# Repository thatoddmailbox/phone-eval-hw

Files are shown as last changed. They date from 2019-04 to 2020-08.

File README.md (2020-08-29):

# phone-eval-hw
The evaluation board for the [phone I built](https://github.com/thatoddmailbox/phone). [View PDF schematic](./thingb-eval-hw.pdf)

This was the first version of the hardware. The idea was to make sure that things were working in a more open (and therefore easier to assemble/test/debug) design before making a smaller, more portable version. It also allowed some problems to be caught and addressed for the next revision.

There are a [couple of known issues](https://github.com/thatoddmailbox/phone-eval-hw/issues/1) with this hardware. The biggest issue is that the battery charging IC, while theoretically capable of charging the battery at 1A, quickly gets too hot and throttles itself when charging. These issues were fixed in the [next revision](https://github.com/thatoddmailbox/phone-hw), which also had the correct form factor.

(note: this was originally called thingb-eval-hw because I thought I'd come up with a more creative name than "phone". I did not.)

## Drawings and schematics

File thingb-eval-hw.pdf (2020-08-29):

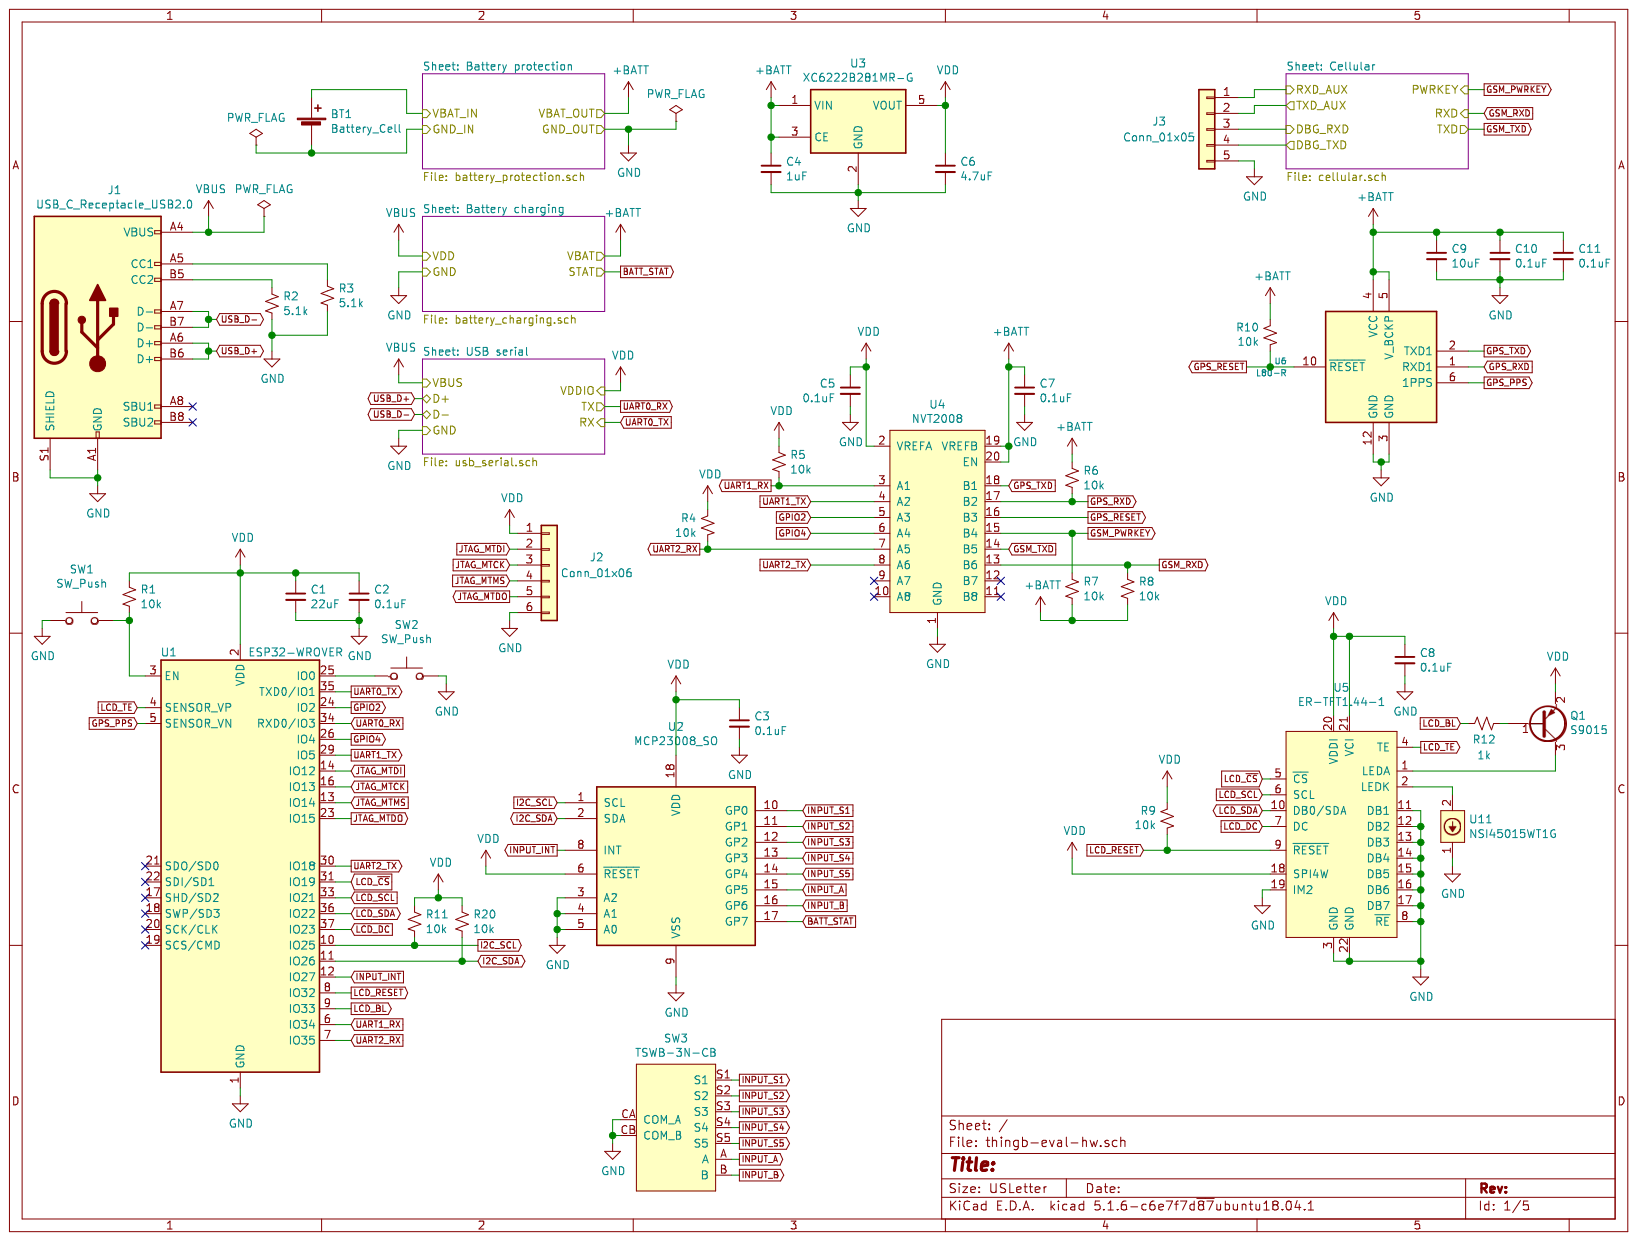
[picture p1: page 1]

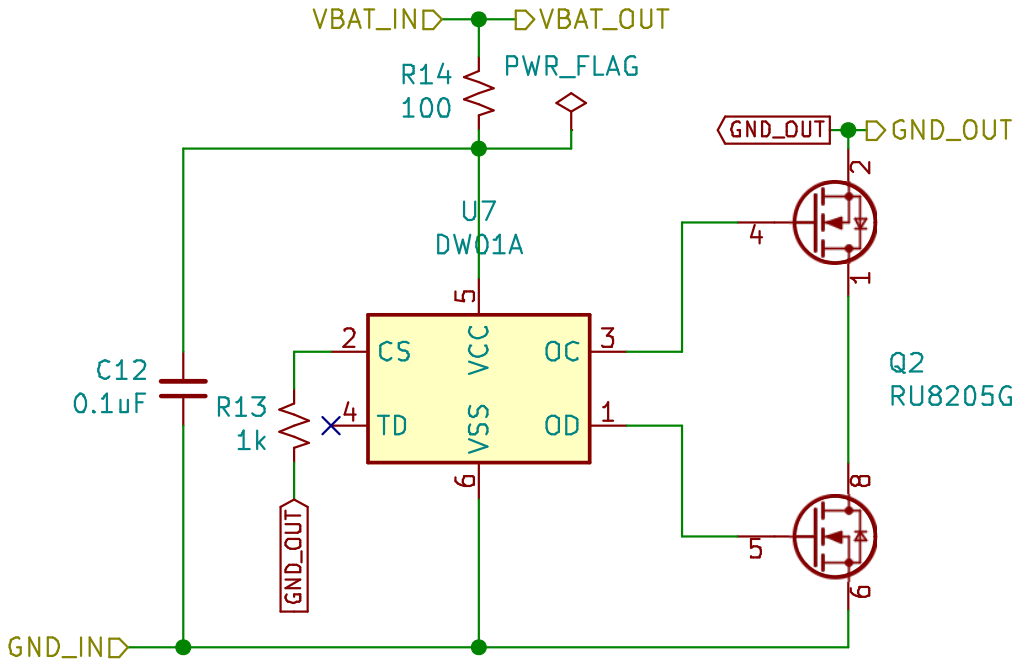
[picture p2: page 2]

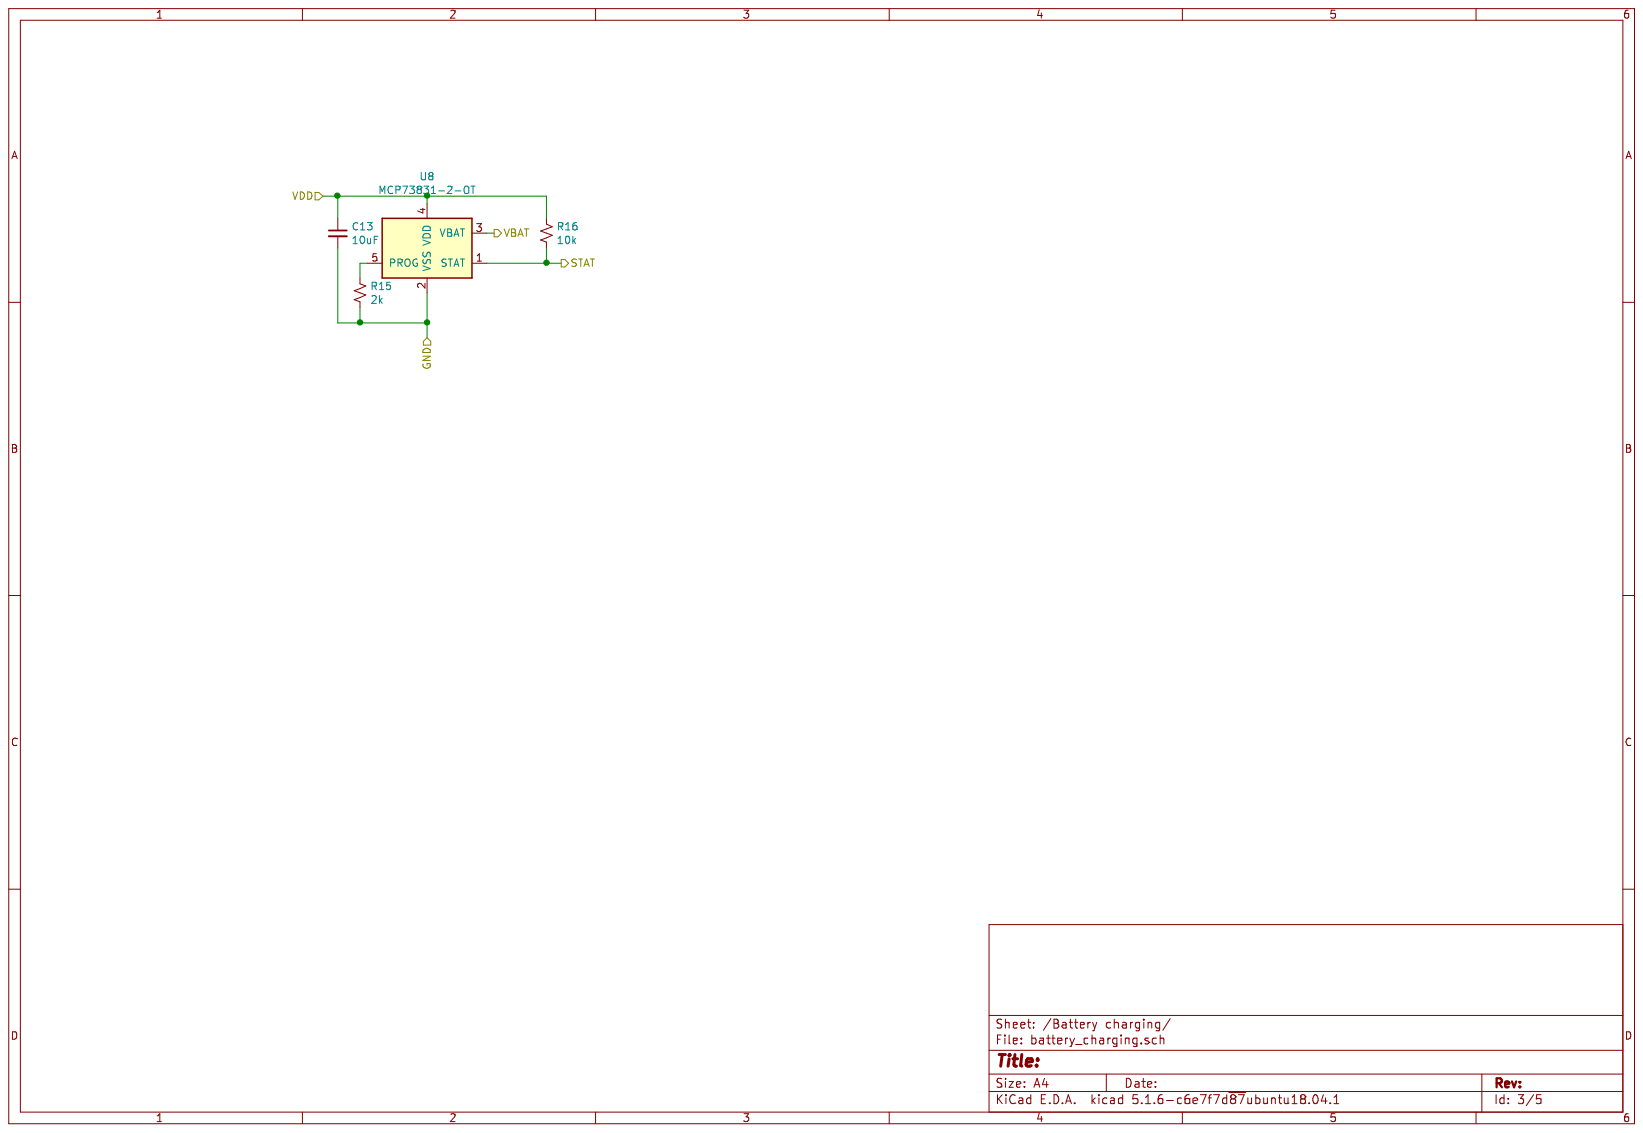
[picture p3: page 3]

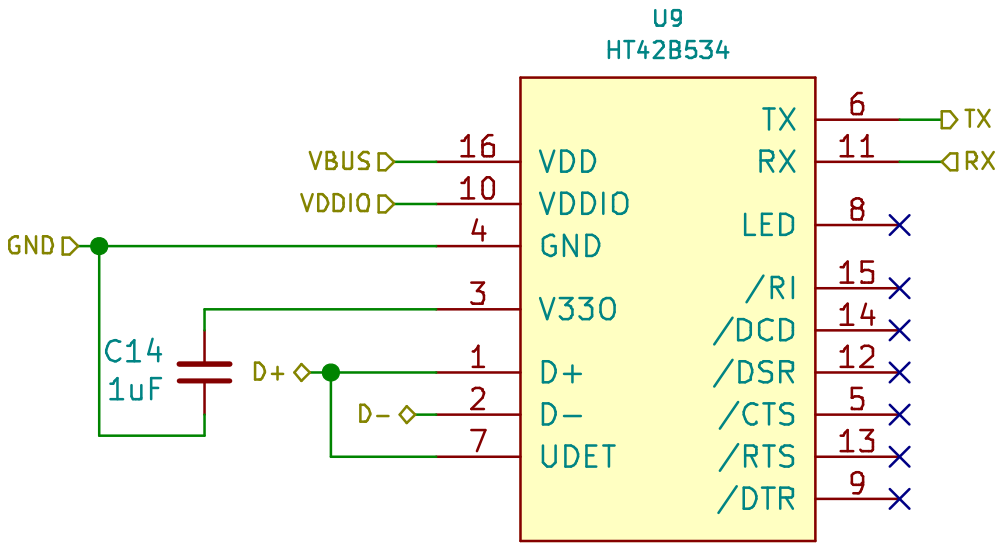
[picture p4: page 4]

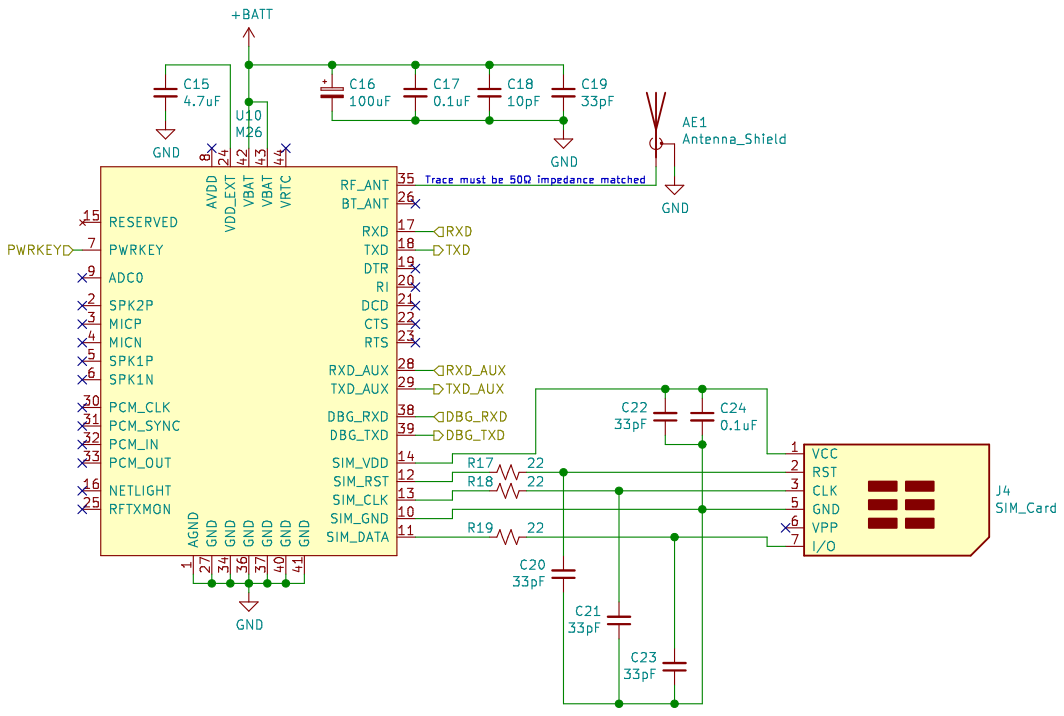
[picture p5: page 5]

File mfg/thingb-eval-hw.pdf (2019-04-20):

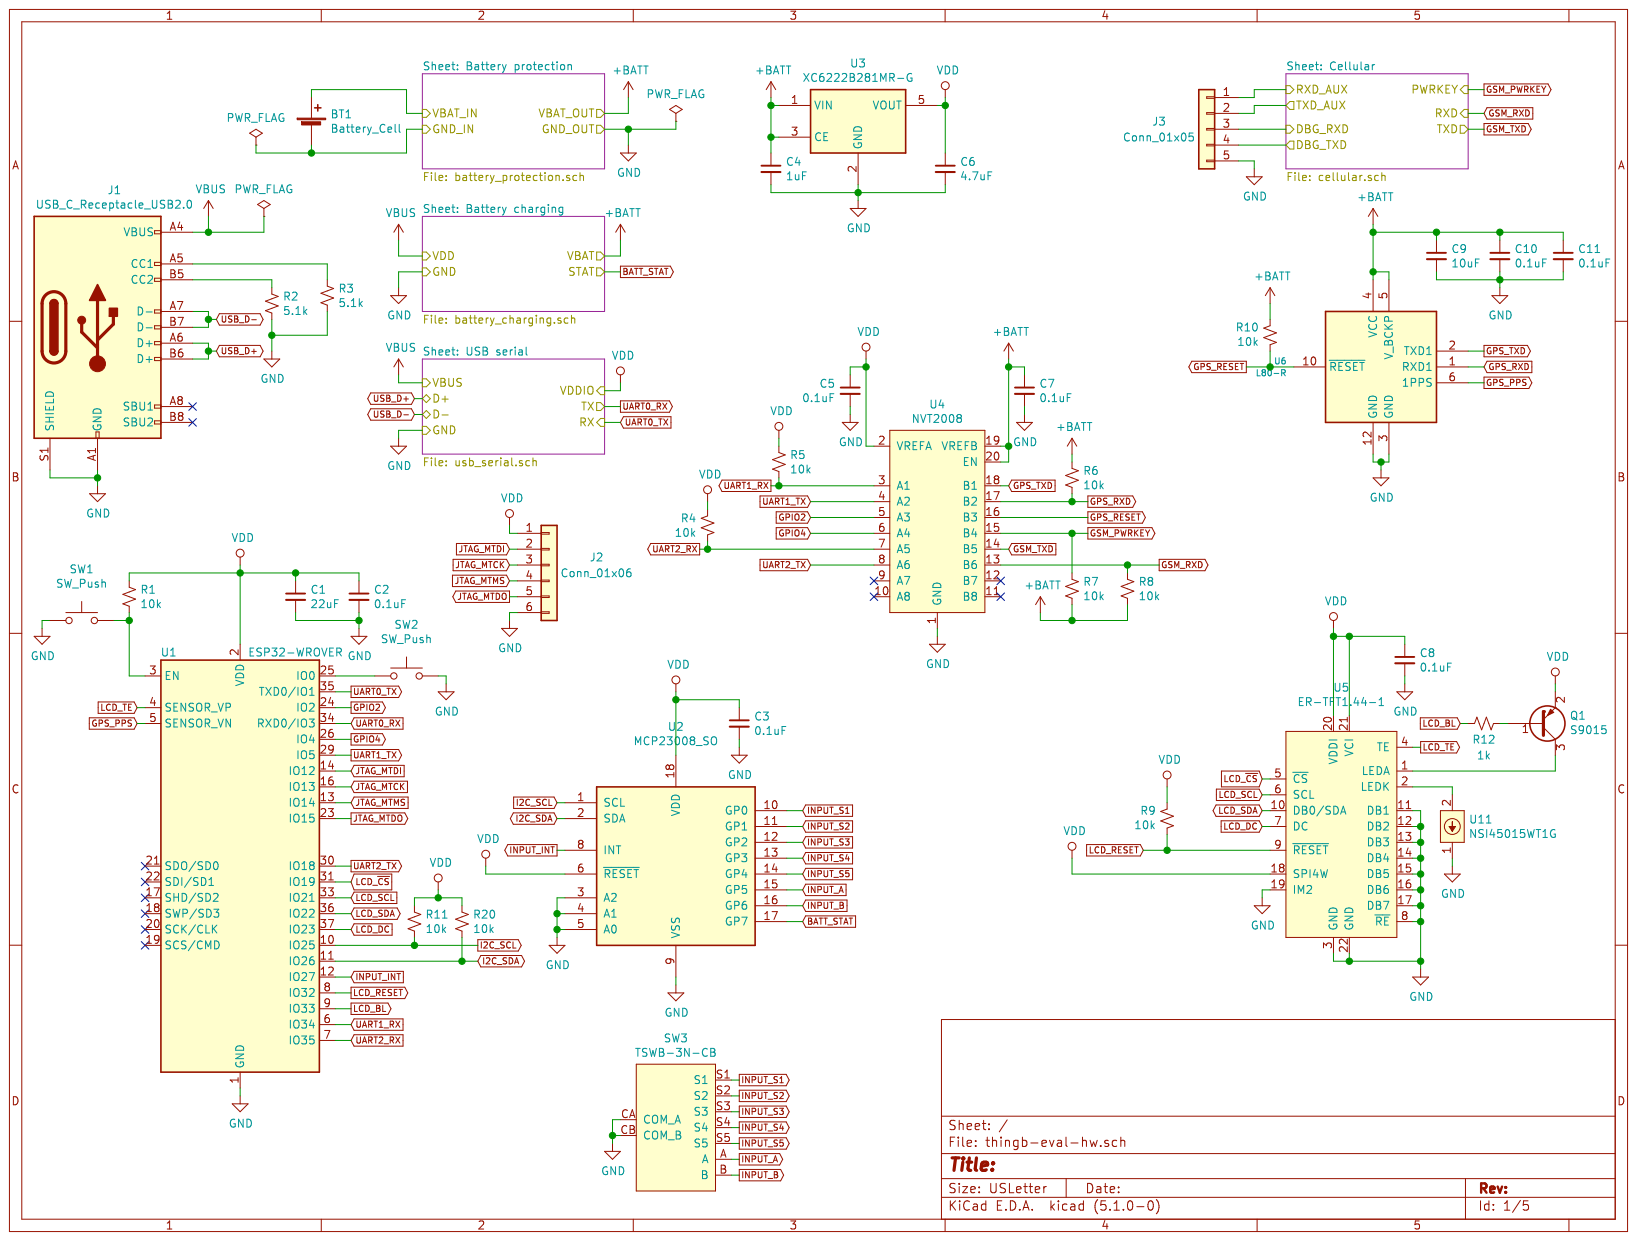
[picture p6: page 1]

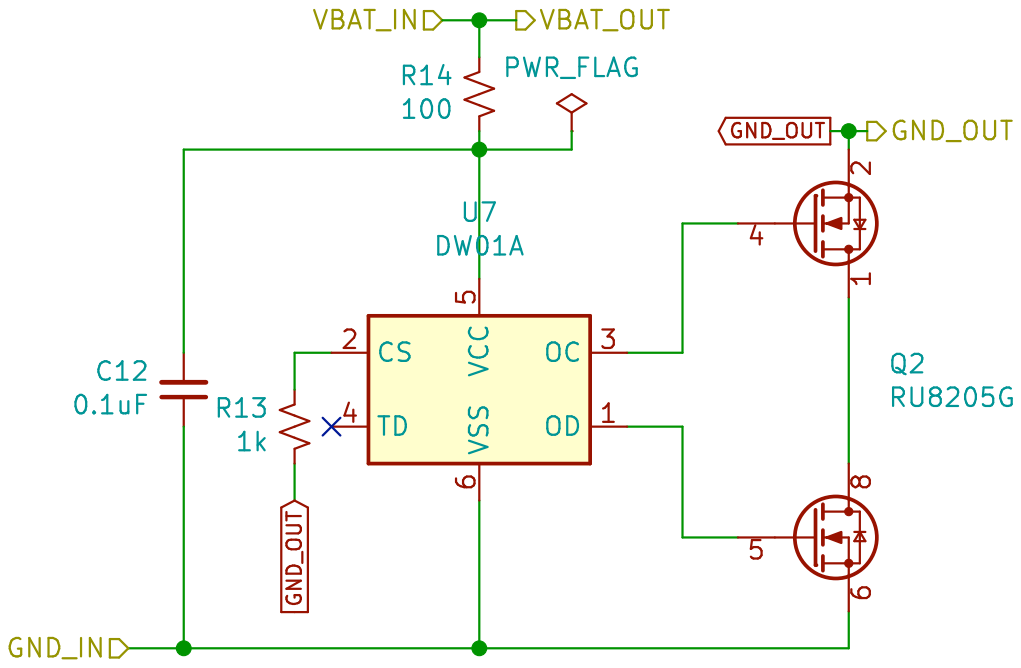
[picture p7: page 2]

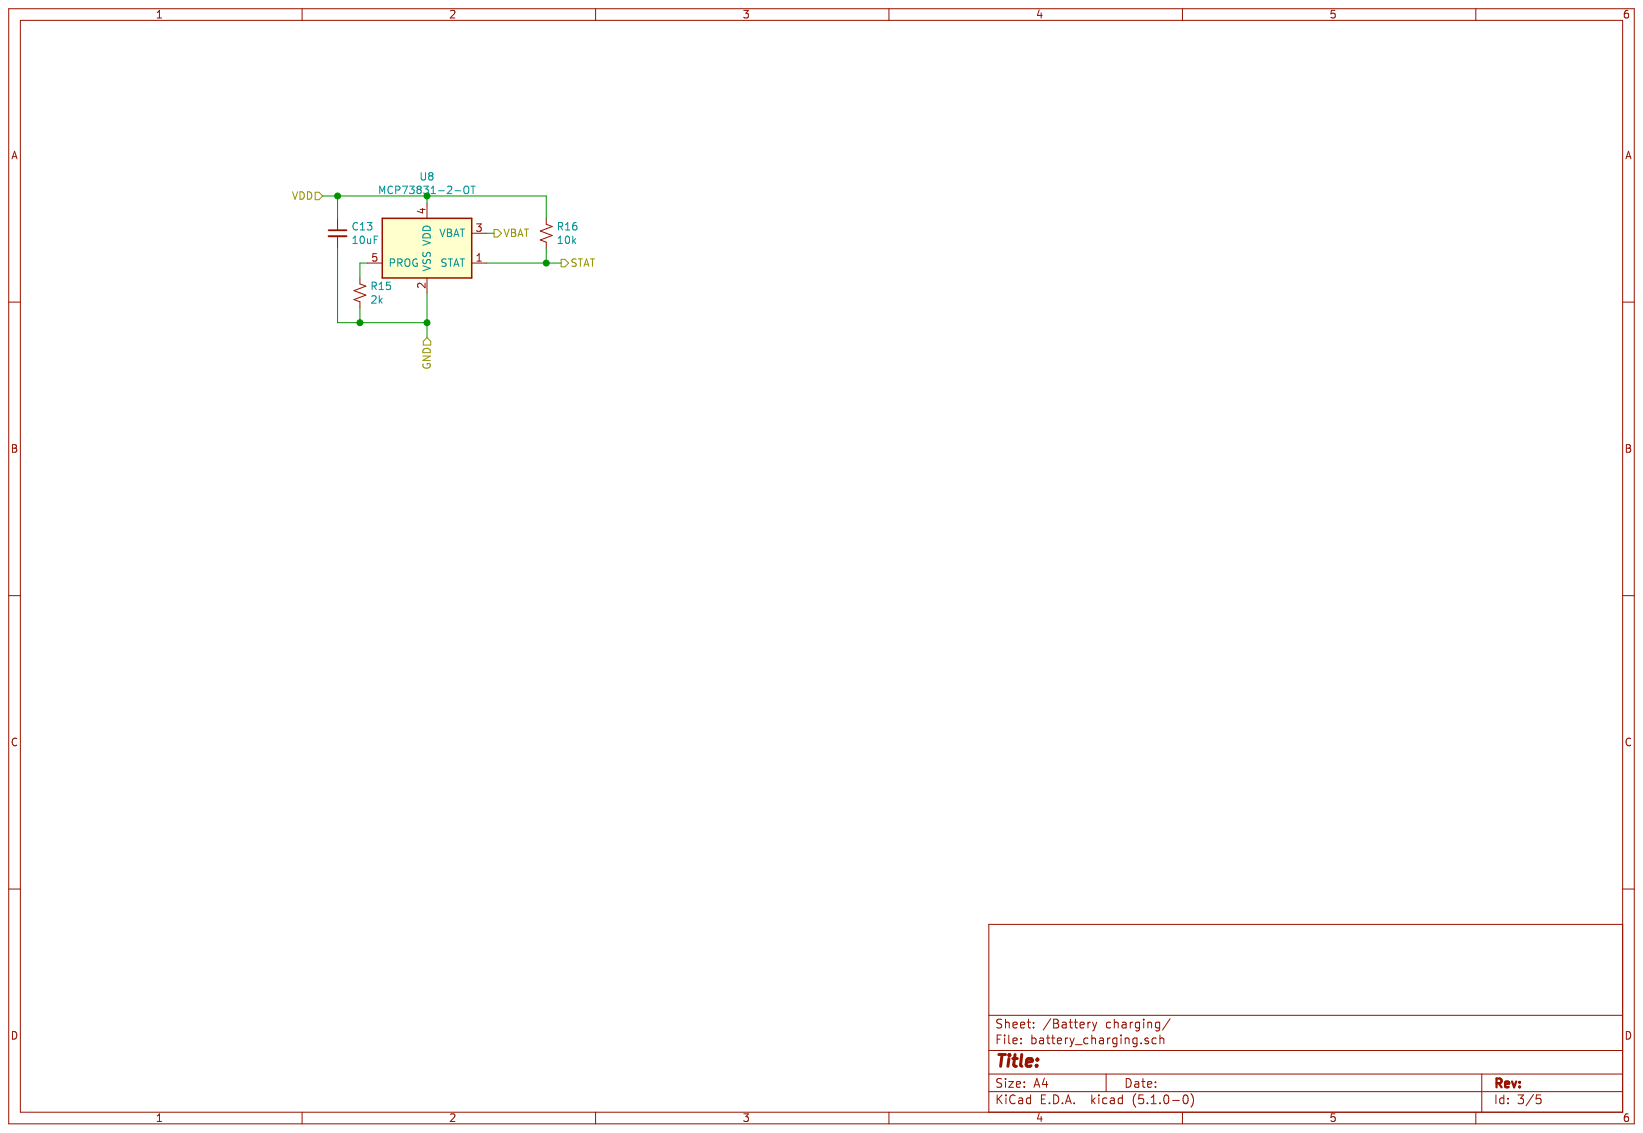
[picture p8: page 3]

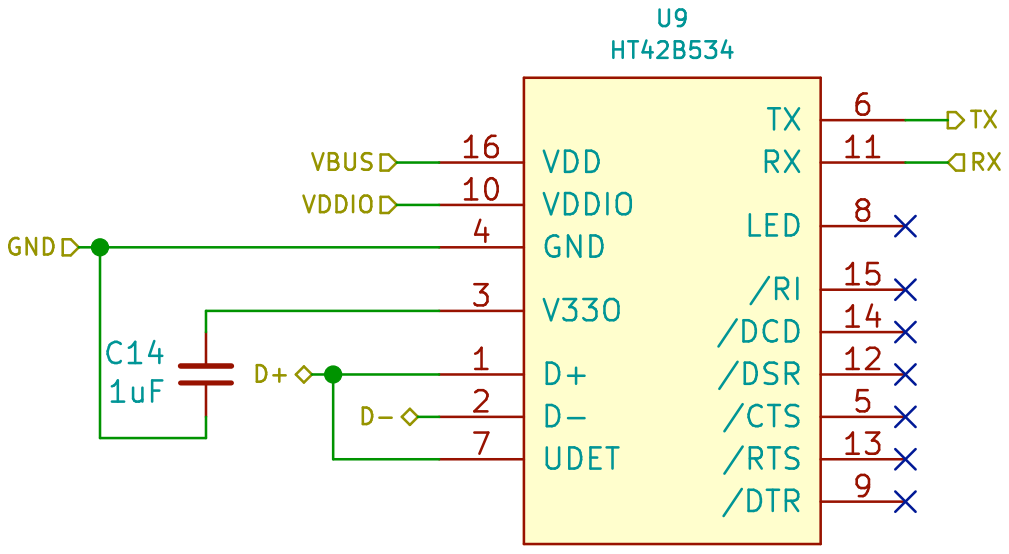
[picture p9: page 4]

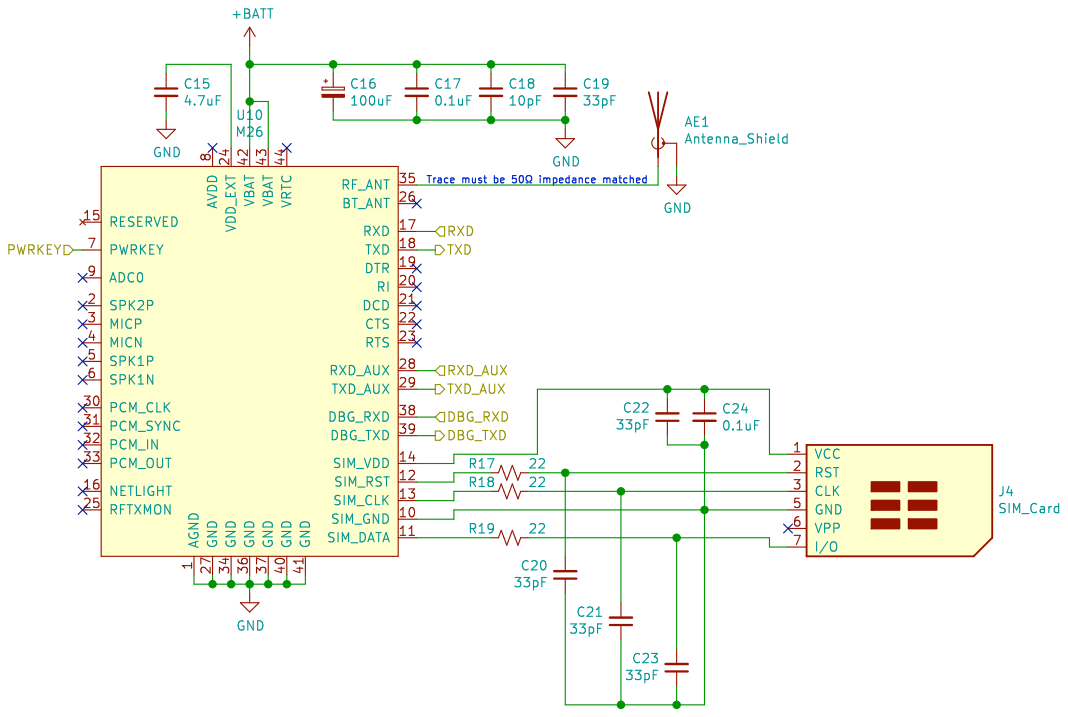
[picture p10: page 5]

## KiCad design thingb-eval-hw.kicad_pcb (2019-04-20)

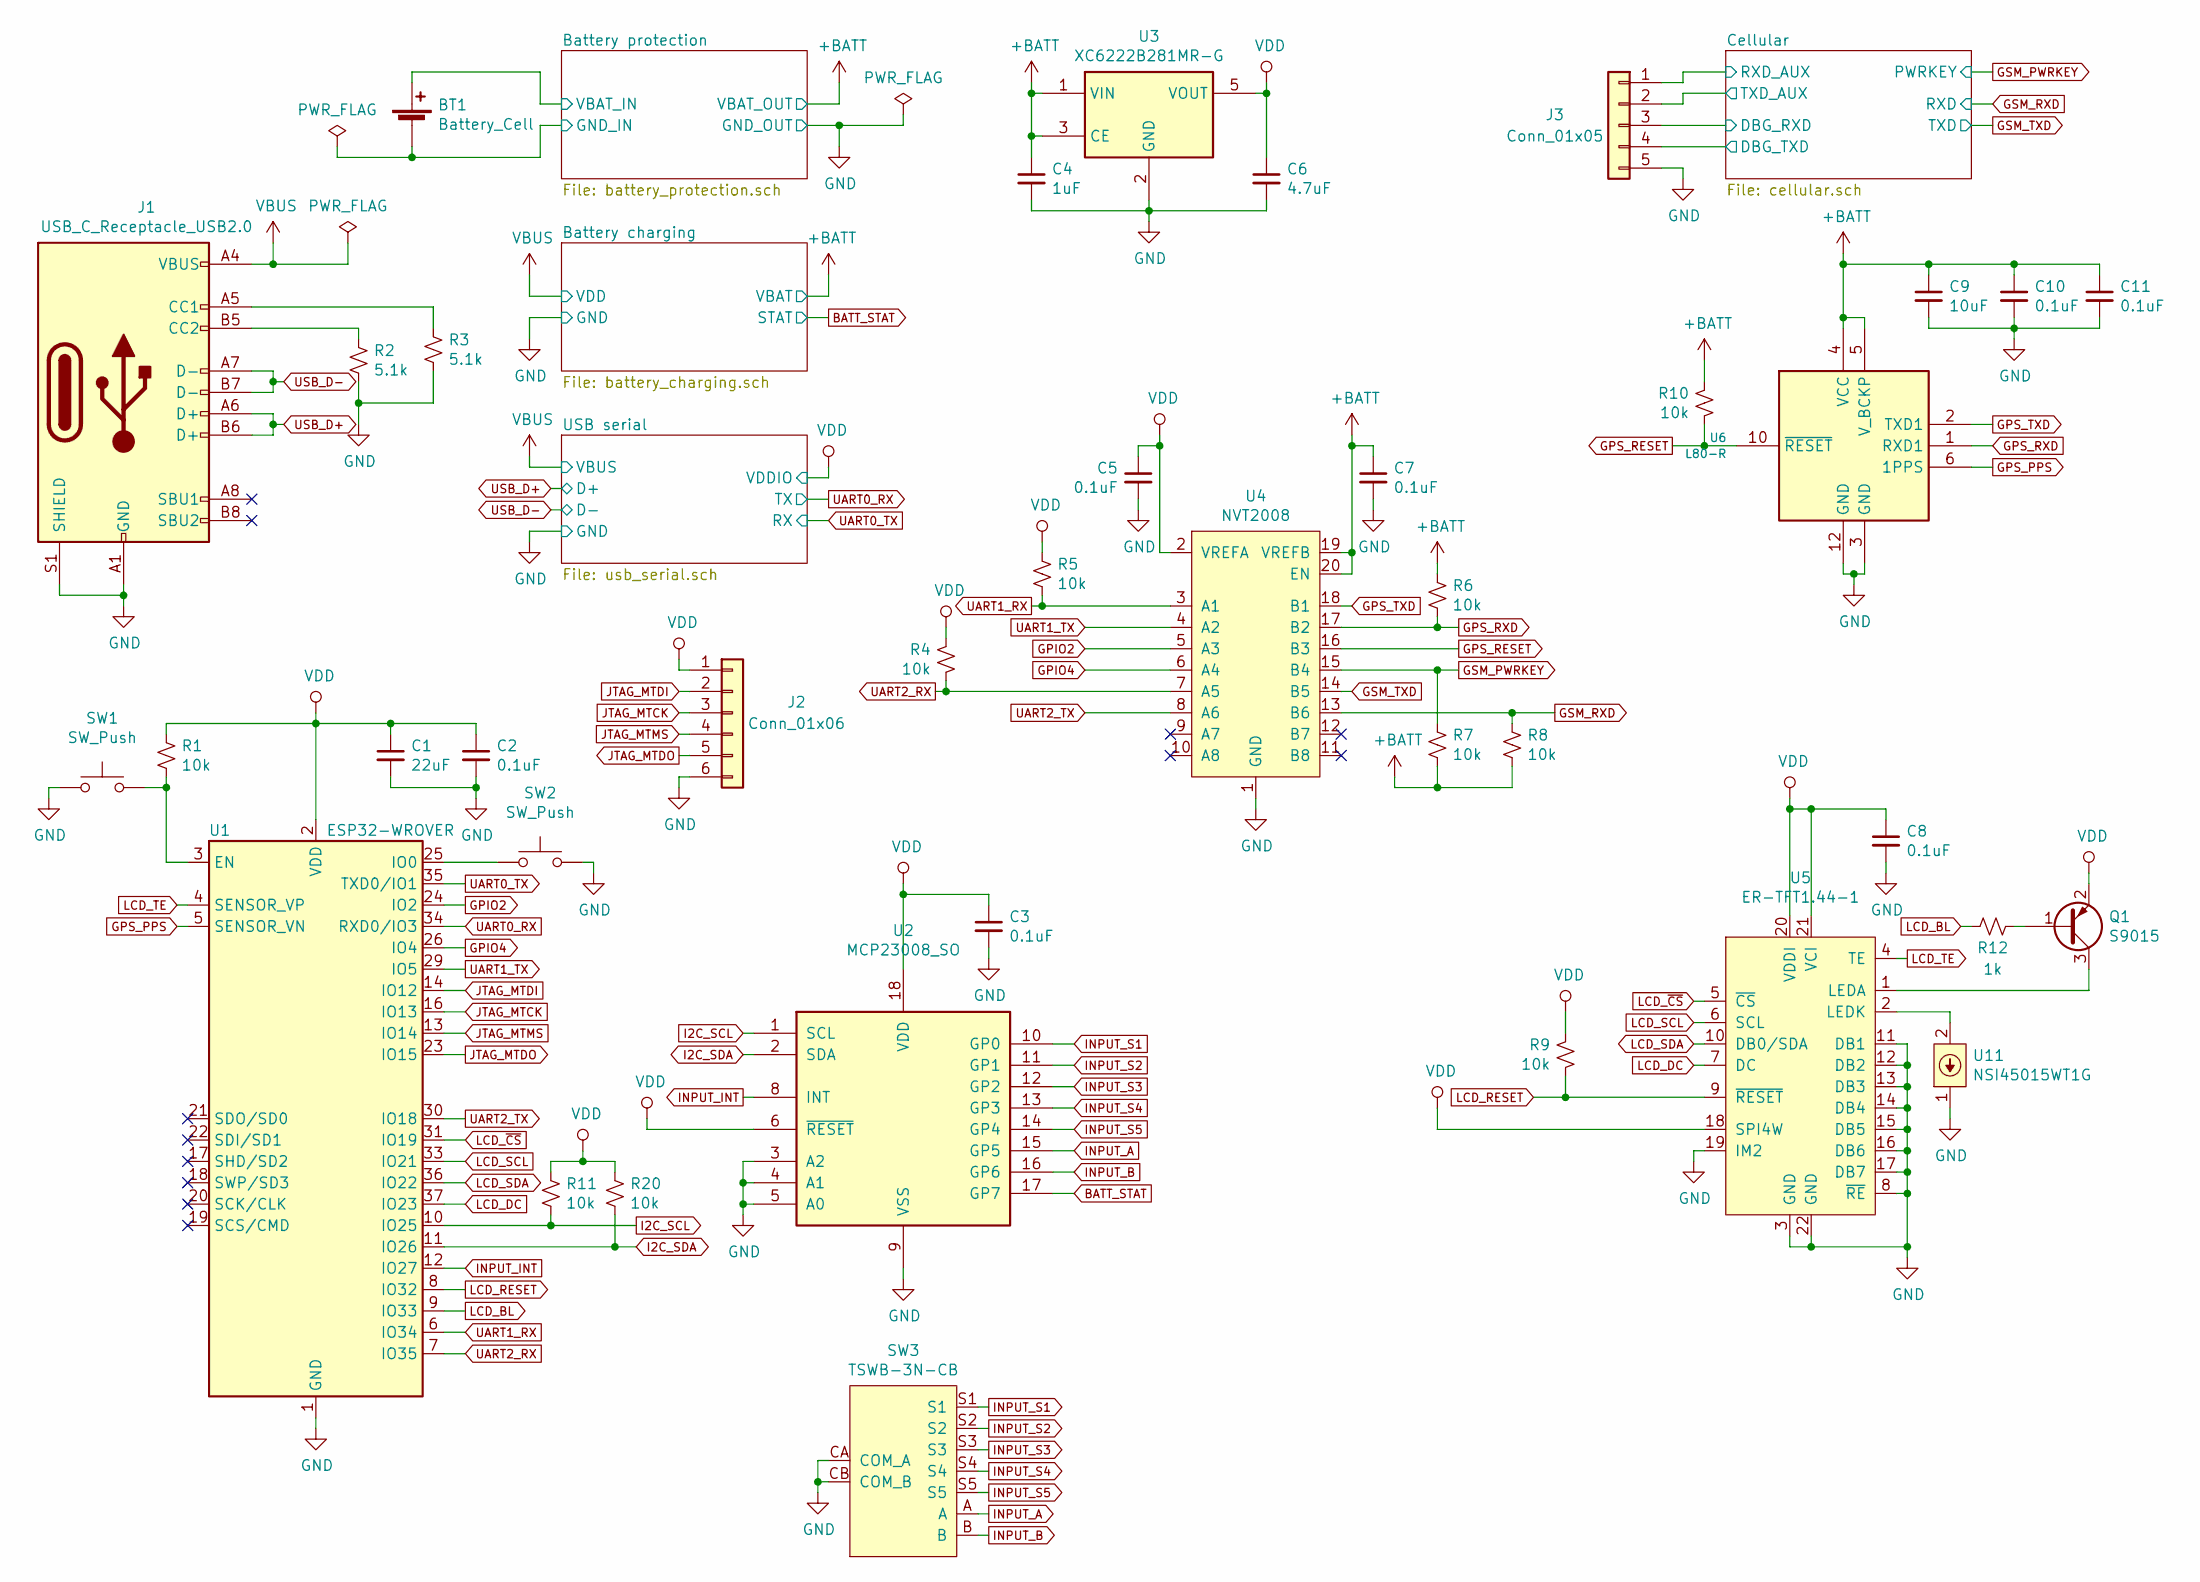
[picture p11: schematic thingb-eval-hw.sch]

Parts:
BT1: Battery_Cell; PinHeader_1x02_P2.54mm_Vertical
C1: 22uF; C_0603_1608Metric_Pad1.05x0.95mm_HandSolder
C2, C3, C5, C7, C8, C10, C11: 0.1uF; C_0603_1608Metric_Pad1.05x0.95mm_HandSolder
C4: 1uF; C_0603_1608Metric_Pad1.05x0.95mm_HandSolder
C6: 4.7uF; C_0603_1608Metric_Pad1.05x0.95mm_HandSolder
C9: 10uF; C_0603_1608Metric_Pad1.05x0.95mm_HandSolder
J1: USB_C_Receptacle_USB2.0; U262-16XN-4BVC11
J2: Conn_01x06; PinHeader_1x06_P2.54mm_Vertical
J3: Conn_01x05; PinHeader_1x05_P2.54mm_Vertical
Q1: S9015; SOT-23_Handsoldering
R1, R4, R5, R6, R7, R8, R9, R10, R11, R20: 10k; R_0603_1608Metric_Pad1.05x0.95mm_HandSolder
R2, R3: 5.1k; R_0603_1608Metric_Pad1.05x0.95mm_HandSolder
R12: 1k; R_0603_1608Metric_Pad1.05x0.95mm_HandSolder
SW1, SW2: SW_Push; SW_SPST_EVQPE1
SW3: TSWB-3N-CB
U1: ESP32-WROVER
U2: MCP23008_SO; SOIC-18W_7.5x11.6mm_P1.27mm
U3: XC6222B281MR-G; SOT-23-5
U4: NVT2008; TSSOP-20_4.4x6.5mm_P0.65mm
U5: ER-TFT1.44-1
U6: L80-R
U11: NSI45015WT1G; D_SOD-123

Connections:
+BATT: BT1.1 (+), C4.1, C7.1, C9.1, C10.1, C11.1, R6.1, R7.2, R8.2, R10.2, U3.1 (VIN), U3.3 (CE), U4.19 (VREFB), U4.20 (EN), U6.4 (VCC), U6.5 (V_BCKP); also elsewhere on the board
/Battery protection/GND_IN: BT1.2 (-); also elsewhere on the board
/Cellular/DBG_RXD: J3.3; also elsewhere on the board
/Cellular/DBG_TXD: J3.4; also elsewhere on the board
/Cellular/RXD_AUX: J3.1; also elsewhere on the board
/Cellular/TXD_AUX: J3.2; also elsewhere on the board
BATT_STAT: U2.17 (GP7); also elsewhere on the board
GND_OUT: C1.2, C2.2, C3.2, C4.2, C5.2, C6.2, C7.2, C8.2, C9.2, C10.2, C11.2, J1.A1 (GND), J1.A12 (GND), J1.B1 (GND), J1.B12 (GND), J1.S1 (SHIELD), J2.6, J3.5, R2.2, R3.2, SW1.2, SW2.2, SW3.CA (COM_A), SW3.CB (COM_B), U1.1 (GND), U1.15 (GND), U1.38 (GND), U2.3 (A2), U2.4 (A1), U2.5 (A0), U2.9 (VSS), U3.2 (GND), U4.1 (GND), U5.3 (GND), U5.8 (~RE), U5.11 (DB1), U5.12 (DB2), U5.13 (DB3), U5.14 (DB4), U5.15 (DB5), U5.16 (DB6), U5.17 (DB7), U5.19 (IM2), U5.22 (GND), U6.3 (GND), U6.12 (GND), U11.1; also elsewhere on the board
GPIO2: U1.24 (IO2), U4.5 (A3)
GPIO4: U1.26 (IO4), U4.6 (A4)
GPS_PPS: U1.5 (SENSOR_VN), U6.6 (1PPS)
GPS_RESET: R10.1, U4.16 (B3), U6.10 (~RESET)
GPS_RXD: R6.2, U4.17 (B2), U6.1 (RXD1)
GPS_TXD: U4.18 (B1), U6.2 (TXD1)
GSM_PWRKEY: R7.1, U4.15 (B4); also elsewhere on the board
GSM_RXD: R8.1, U4.13 (B6); also elsewhere on the board
GSM_TXD: U4.14 (B5); also elsewhere on the board
I2C_SCL: R11.2, U1.10 (IO25), U2.1 (SCL)
I2C_SDA: R20.2, U1.11 (IO26), U2.2 (SDA)
INPUT_A: SW3.A, U2.15 (GP5)
INPUT_B: SW3.B, U2.16 (GP6)
INPUT_INT: U1.12 (IO27), U2.8 (INT)
INPUT_S1: SW3.S1, U2.10 (GP0)
INPUT_S2: SW3.S2, U2.11 (GP1)
INPUT_S3: SW3.S3, U2.12 (GP2)
INPUT_S4: SW3.S4, U2.13 (GP3)
INPUT_S5: SW3.S5, U2.14 (GP4)
JTAG_MTCK: J2.3, U1.16 (IO13)
JTAG_MTDI: J2.2, U1.14 (IO12)
JTAG_MTDO: J2.5, U1.23 (IO15)
JTAG_MTMS: J2.4, U1.13 (IO14)
LCD_BL: R12.2, U1.9 (IO33)
LCD_DC: U1.37 (IO23), U5.7 (DC)
LCD_RESET: R9.1, U1.8 (IO32), U5.9 (~RESET)
LCD_SCL: U1.33 (IO21), U5.6 (SCL)
LCD_SDA: U1.36 (IO22), U5.10 (DB0/SDA)
LCD_TE: U1.4 (SENSOR_VP), U5.4 (TE)
LCD_~CS: U1.31 (IO19), U5.5 (~CS)
unnamed: J1.A5 (CC1), R3.1
unnamed: J1.B5 (CC2), R2.1
unnamed: Q1.1 (B), R12.1
unnamed: Q1.3 (C), U5.1 (LEDA)
unnamed: R1.2, SW1.1, U1.3 (EN)
unnamed: SW2.1, U1.25 (IO0)
unnamed: U5.2 (LEDK), U11.2
UART0_RX: U1.34 (RXD0/IO3); also elsewhere on the board
UART0_TX: U1.35 (TXD0/IO1); also elsewhere on the board
UART1_RX: R5.2, U1.6 (IO34), U4.3 (A1)
UART1_TX: U1.29 (IO5), U4.4 (A2)
UART2_RX: R4.2, U1.7 (IO35), U4.7 (A5)
UART2_TX: U1.30 (IO18), U4.8 (A6)
USB_D+: J1.A6 (D+), J1.B6 (D+); also elsewhere on the board
USB_D-: J1.A7 (D-), J1.B7 (D-); also elsewhere on the board
VBUS: J1.A4 (VBUS), J1.A9 (VBUS), J1.B4 (VBUS), J1.B9 (VBUS); also elsewhere on the board
VDD: C1.1, C2.1, C3.1, C5.1, C6.1, C8.1, J2.1, Q1.2 (E), R1.1, R4.1, R5.1, R9.2, R11.1, R20.1, U1.2 (VDD), U2.6 (~RESET~), U2.18 (VDD), U3.5 (VOUT), U4.2 (VREFA), U5.18 (SPI4W), U5.20 (VDDI), U5.21 (VCI); also elsewhere on the board

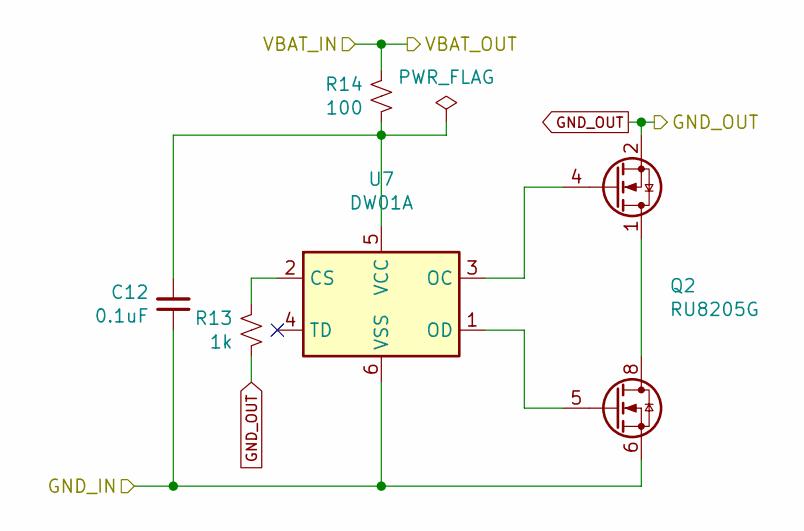
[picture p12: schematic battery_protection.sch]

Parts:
C12: 0.1uF; C_0603_1608Metric_Pad1.05x0.95mm_HandSolder
Q2: RU8205G; TSSOP-8_4.4x3mm_P0.65mm
R13: 1k; R_0603_1608Metric_Pad1.05x0.95mm_HandSolder
R14: 100; R_0603_1608Metric_Pad1.05x0.95mm_HandSolder
U7: DW01A; SOT-23-6

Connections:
+BATT: R14.2; also elsewhere on the board
/Battery protection/GND_IN: C12.1, Q2.6 (S2), Q2.7 (S2), U7.6 (VSS); also elsewhere on the board
GND_OUT: Q2.2 (S1), Q2.3 (S1), R13.1; also elsewhere on the board
unnamed: C12.2, R14.1, U7.5 (VCC)
unnamed: Q2.1 (D1), Q2.8 (D2)
unnamed: Q2.4 (G1), U7.3 (OC)
unnamed: Q2.5 (G2), U7.1 (OD)
unnamed: R13.2, U7.2 (CS)

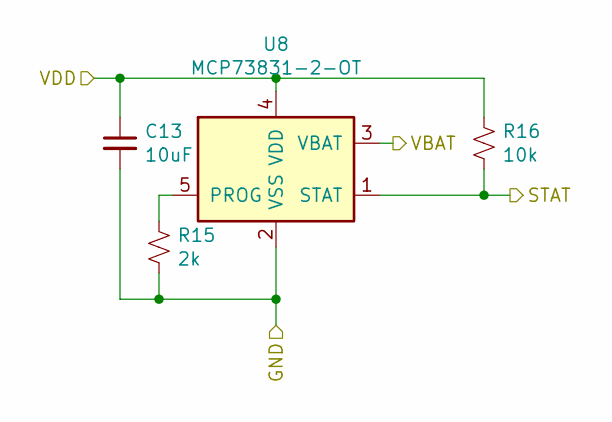
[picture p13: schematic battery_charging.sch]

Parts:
C13: 10uF; C_0603_1608Metric_Pad1.05x0.95mm_HandSolder
R15: 2k; R_0603_1608Metric_Pad1.05x0.95mm_HandSolder
R16: 10k; R_0603_1608Metric_Pad1.05x0.95mm_HandSolder
U8: MCP73831-2-OT; SOT-23-5

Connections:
+BATT: U8.3 (VBAT); also elsewhere on the board
BATT_STAT: R16.2, U8.1 (STAT); also elsewhere on the board
GND_OUT: C13.2, R15.2, U8.2 (VSS); also elsewhere on the board
unnamed: R15.1, U8.5 (PROG)
VBUS: C13.1, R16.1, U8.4 (VDD); also elsewhere on the board

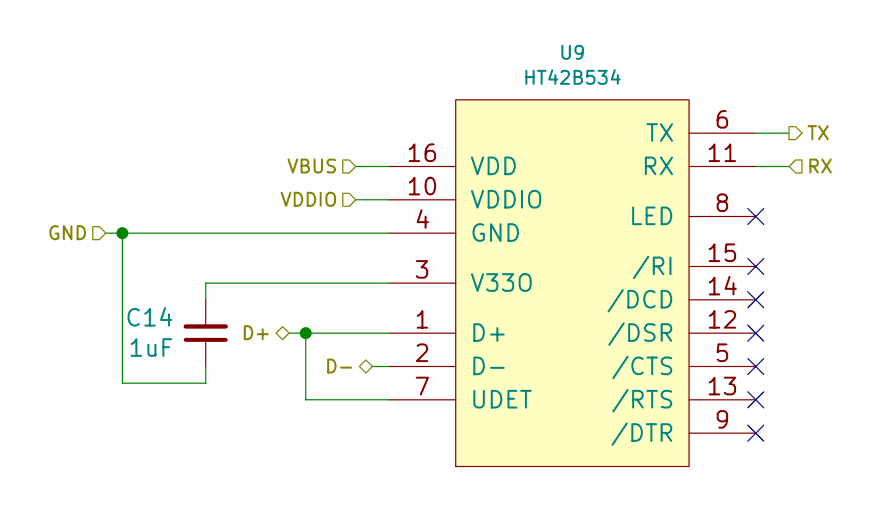
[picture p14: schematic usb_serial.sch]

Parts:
C14: 1uF; C_0603_1608Metric_Pad1.05x0.95mm_HandSolder
U9: HT42B534; SOIC-16_3.9x9.9mm_P1.27mm

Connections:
GND_OUT: C14.1, U9.4 (GND); also elsewhere on the board
unnamed: C14.2, U9.3 (V33O)
UART0_RX: U9.6 (TX); also elsewhere on the board
UART0_TX: U9.11 (RX); also elsewhere on the board
USB_D+: U9.1 (D+), U9.7 (UDET); also elsewhere on the board
USB_D-: U9.2 (D-); also elsewhere on the board
VBUS: U9.16 (VDD); also elsewhere on the board
VDD: U9.10 (VDDIO); also elsewhere on the board

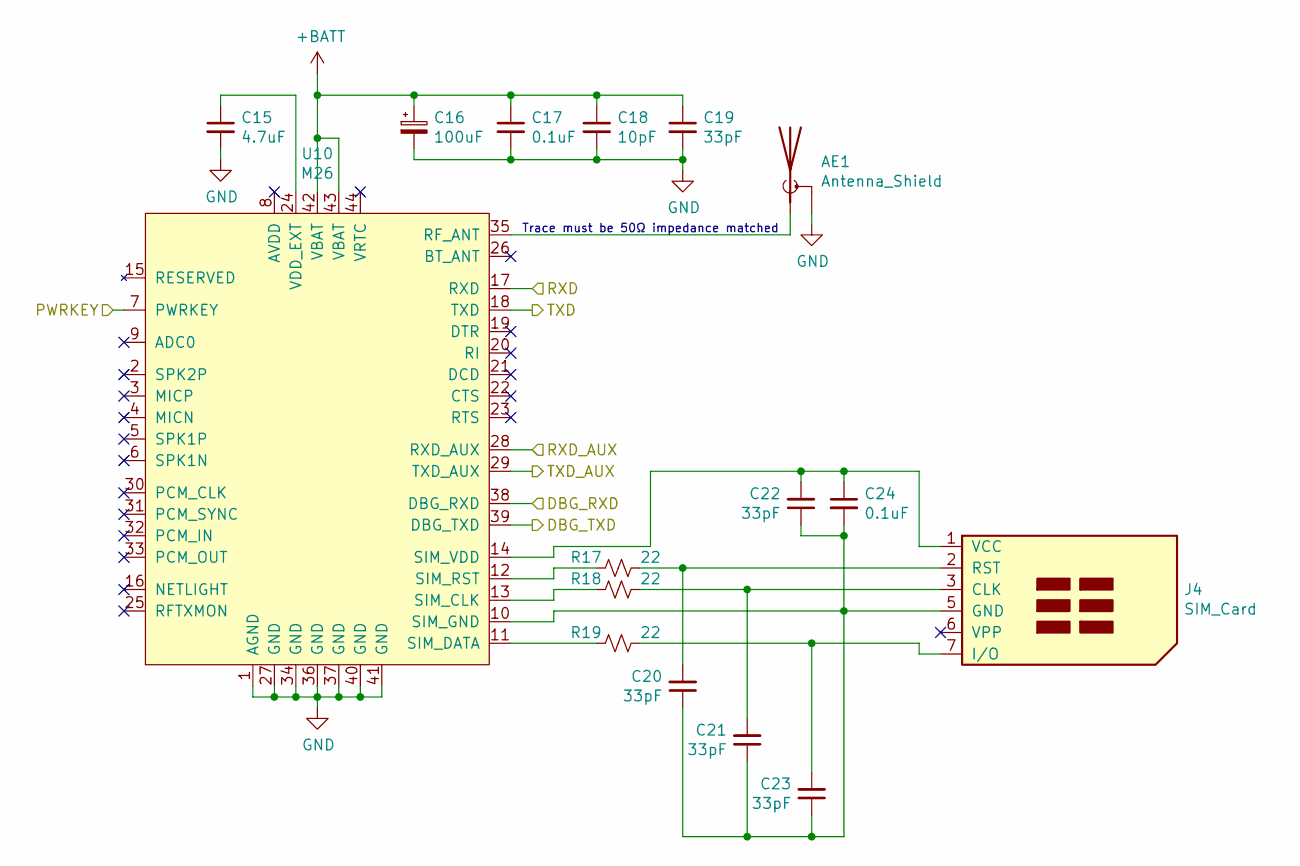
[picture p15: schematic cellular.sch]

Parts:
AE1: Antenna_Shield; U.FL_Molex_MCRF_73412-0110_Vertical
C15: 4.7uF; C_0603_1608Metric_Pad1.05x0.95mm_HandSolder
C16: 100uF; CP_EIA-3528-15_AVX-H_Pad1.50x2.35mm_HandSolder
C17, C24: 0.1uF; C_0603_1608Metric_Pad1.05x0.95mm_HandSolder
C18: 10pF; C_0603_1608Metric_Pad1.05x0.95mm_HandSolder
C19, C20, C21, C22, C23: 33pF; C_0603_1608Metric_Pad1.05x0.95mm_HandSolder
J4: SIM_Card; 7112S0815X19LF
R17, R18, R19: 22; R_0603_1608Metric_Pad1.05x0.95mm_HandSolder
U10: M26

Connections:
+BATT: C16.1, C17.1, C18.1, C19.1, U10.42 (VBAT), U10.43 (VBAT); also elsewhere on the board
/Cellular/DBG_RXD: U10.38 (DBG_RXD); also elsewhere on the board
/Cellular/DBG_TXD: U10.39 (DBG_TXD); also elsewhere on the board
/Cellular/RXD_AUX: U10.28 (RXD_AUX); also elsewhere on the board
/Cellular/TXD_AUX: U10.29 (TXD_AUX); also elsewhere on the board
GND_OUT: AE1.2 (Shield), C15.2, C16.2, C17.2, C18.2, C19.2, U10.1 (AGND), U10.27 (GND), U10.34 (GND), U10.36 (GND), U10.37 (GND), U10.40 (GND), U10.41 (GND); also elsewhere on the board
GSM_PWRKEY: U10.7 (PWRKEY); also elsewhere on the board
GSM_RXD: U10.17 (RXD); also elsewhere on the board
GSM_TXD: U10.18 (TXD); also elsewhere on the board
unnamed: AE1.1 (A), U10.35 (RF_ANT)
unnamed: C15.1, U10.24 (VDD_EXT)
unnamed: C20.1, C21.1, C22.1, C23.1, C24.2, J4.5 (GND), U10.10 (SIM_GND)
unnamed: C20.2, J4.2 (RST), R17.1
unnamed: C21.2, J4.3 (CLK), R18.1
unnamed: C22.2, C24.1, J4.1 (VCC), U10.14 (SIM_VDD)
unnamed: C23.2, J4.7 (I/O), R19.1
unnamed: R17.2, U10.12 (SIM_RST)
unnamed: R18.2, U10.13 (SIM_CLK)
unnamed: R19.2, U10.11 (SIM_DATA)

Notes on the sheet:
Trace must be 50Ω impedance matched

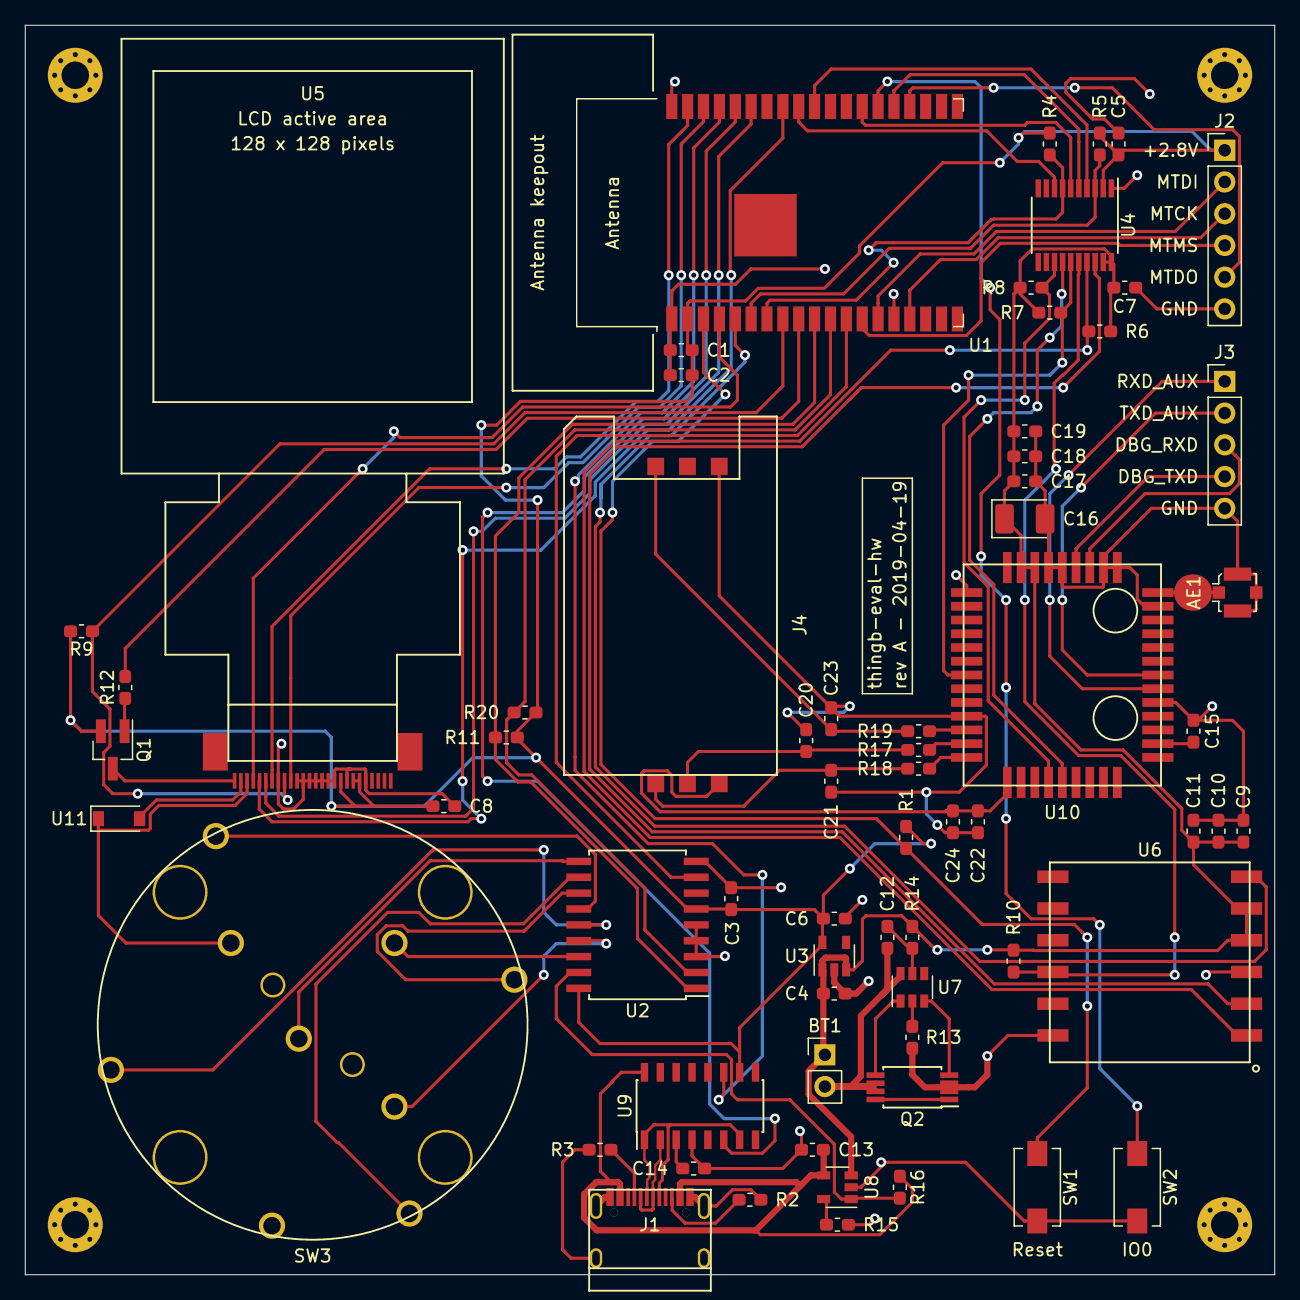
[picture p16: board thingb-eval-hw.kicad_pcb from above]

Board: 2 copper layers, 100.0 x 100.0 mm, 66 parts (0 on the bottom side), 72 nets.

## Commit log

2019-03-24 commit current schematics
    [battery_charging.sch, battery_protection.sch, thingb-eval-hw.kicad_pcb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]
2019-03-25 add new navigation switch symbol and footprint, remove duplicate L80 footprint
2019-03-26 add symbol and footprint for quectel m26 module
2019-03-27 reorder sim card pins on quectel m26 symbol to match the kicad sim card symbol's order
2019-03-27 add symbols and footprints for eastrising tft display and its connector
2019-03-29 add cellular module, input, display, level shifter, and more to schematic
    [battery_charging.sch, battery_protection.sch, cellular.sch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]
2019-03-30 fix esp32-wrover symbol
2019-03-30 lots of improvements to schematic: fixing decoupling, matching reference designs and recommendations better, connecting pins to esp32 and adding i2c gpio expander
    [battery_charging.sch, battery_protection.sch, cellular.sch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]
2019-03-30 change battery protection to dw01 and 8205 pair
    [battery_protection.sch]
2019-03-30 annotate schematic
    [battery_charging.sch, cellular.sch, thingb-eval-hw.sch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]
2019-03-30 add generated HTML BOM files to gitignore
2019-03-30 fix power flag things
    [battery_protection.sch, cellular.sch, thingb-eval-hw.sch]
2019-03-31 add transistor to control led backlist and flip led anode and cathode positions on tft symbol
    [thingb-eval-hw.sch]
2019-03-31 add footprint for usb type-c connector
2019-03-31 reannotate schematic
    [battery_charging.sch, battery_protection.sch, cellular.sch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]
2019-03-31 add missing holes to usb type-c connector footprint
2019-03-31 add footprint for sim card holder
2019-03-31 associate footprints with all parts
    [battery_charging.sch, battery_protection.sch, cellular.sch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]
2019-04-01 add nsi45015wt1g constant current led driver symbol
2019-04-01 replace backlight resistor with 15 mA constant-current driver, to ensure screen brightness is consistent as battery depletes
    [thingb-eval-hw.sch]
2019-04-04 switch button footprints to be smd switches
    [thingb-eval-hw.sch]
2019-04-09 add power pins to debugging headers and rename usb nets so that kicad recognizes them as a differential pair
    [thingb-eval-hw.sch]
2019-04-15 i am dumb and forgot pullups on the i2c lines
    [thingb-eval-hw.sch]
2019-04-15 lengthen pads of usb-c connector as suggested by datasheet for subsitute part
    https://datasheet.lcsc.com/szlcsc/1903211732_Korean-Hroparts-Elec-TYPE-C-31-M-12_C165948.pdf
2019-04-20 switch programming resistor on lipo charger because it apparently maxes at 500 mA current
    [battery_charging.sch]
2019-04-20 more weird usb-c port footprint changes
2019-04-20 start work on footprint for folded tft module but give up
2019-04-20 modify esp32-wrover footprint to indicate antenna keepout in silkscreen
2019-04-20 add routed pcb layout
    [thingb-eval-hw.kicad_pcb]
2019-04-20 add name, date, and revision to silkscreen
    [thingb-eval-hw.kicad_pcb]
2019-04-20 update version of esp32-wrover footprint used in pcb layout
    [thingb-eval-hw.kicad_pcb]
2019-04-20 actually i'm ordering them today
    [thingb-eval-hw.kicad_pcb]
2019-04-20 generate gerbers
    [thingb-eval-hw-B_Cu.gbr, thingb-eval-hw-B_Mask.gbr, thingb-eval-hw-B_Paste.gbr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]
2020-08-29 add PDF schematic
